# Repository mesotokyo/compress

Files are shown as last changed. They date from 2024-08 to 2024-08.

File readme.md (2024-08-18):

# MST Compress (Optical Compressor) schematic and PCB for KiCAD

(Japanese version is [here](readme_ja.md) / 日本語版は[こちら](readme_ja.md))

## What is this?

KiCAD files to build PCB of the MST Compress (Optical Compressor). These files are created with KiCad 6.0.

For more information about MST Compress, please check https://meso.tokyo/works/compress .

## Notice

This schematic and PCB file need a `ak_misc` footprint library in [mst-kicad-lib](https://github.com/mesotokyo/mst-kicad-lib). 

## DISCLAIMER

FILES IN THIS REPOSITORY ARE PROVIDED "AS IS", WITHOUT WARRANTY OF ANY KIND, EXPRESS OR IMPLIED, INCLUDING BUT NOT LIMITED TO THE WARRANTIES OF MERCHANTABILITY, FITNESS FOR A PARTICULAR PURPOSE AND NONINFRINGEMENT. IN NO EVENT SHALL THE AUTHORS OR COPYRIGHT HOLDERS BE LIABLE FOR ANY CLAIM, DAMAGES OR OTHER LIABILITY, WHETHER IN AN ACTION OF CONTRACT, TORT OR OTHERWISE, ARISING FROM, OUT OF OR IN CONNECTION WITH IN FILES IN THIS REPOSITORY OR THE USE OR OTHER DEALINGS IN FILES IN THIS REPOSITORY.

## License

CC BY 4.0. For more information, please check https://creativecommons.org/licenses/by/4.0/ .

## Author

MST/mesotokyo

 - https://meso.tokyo/
 - https://x.com/mesotokyox

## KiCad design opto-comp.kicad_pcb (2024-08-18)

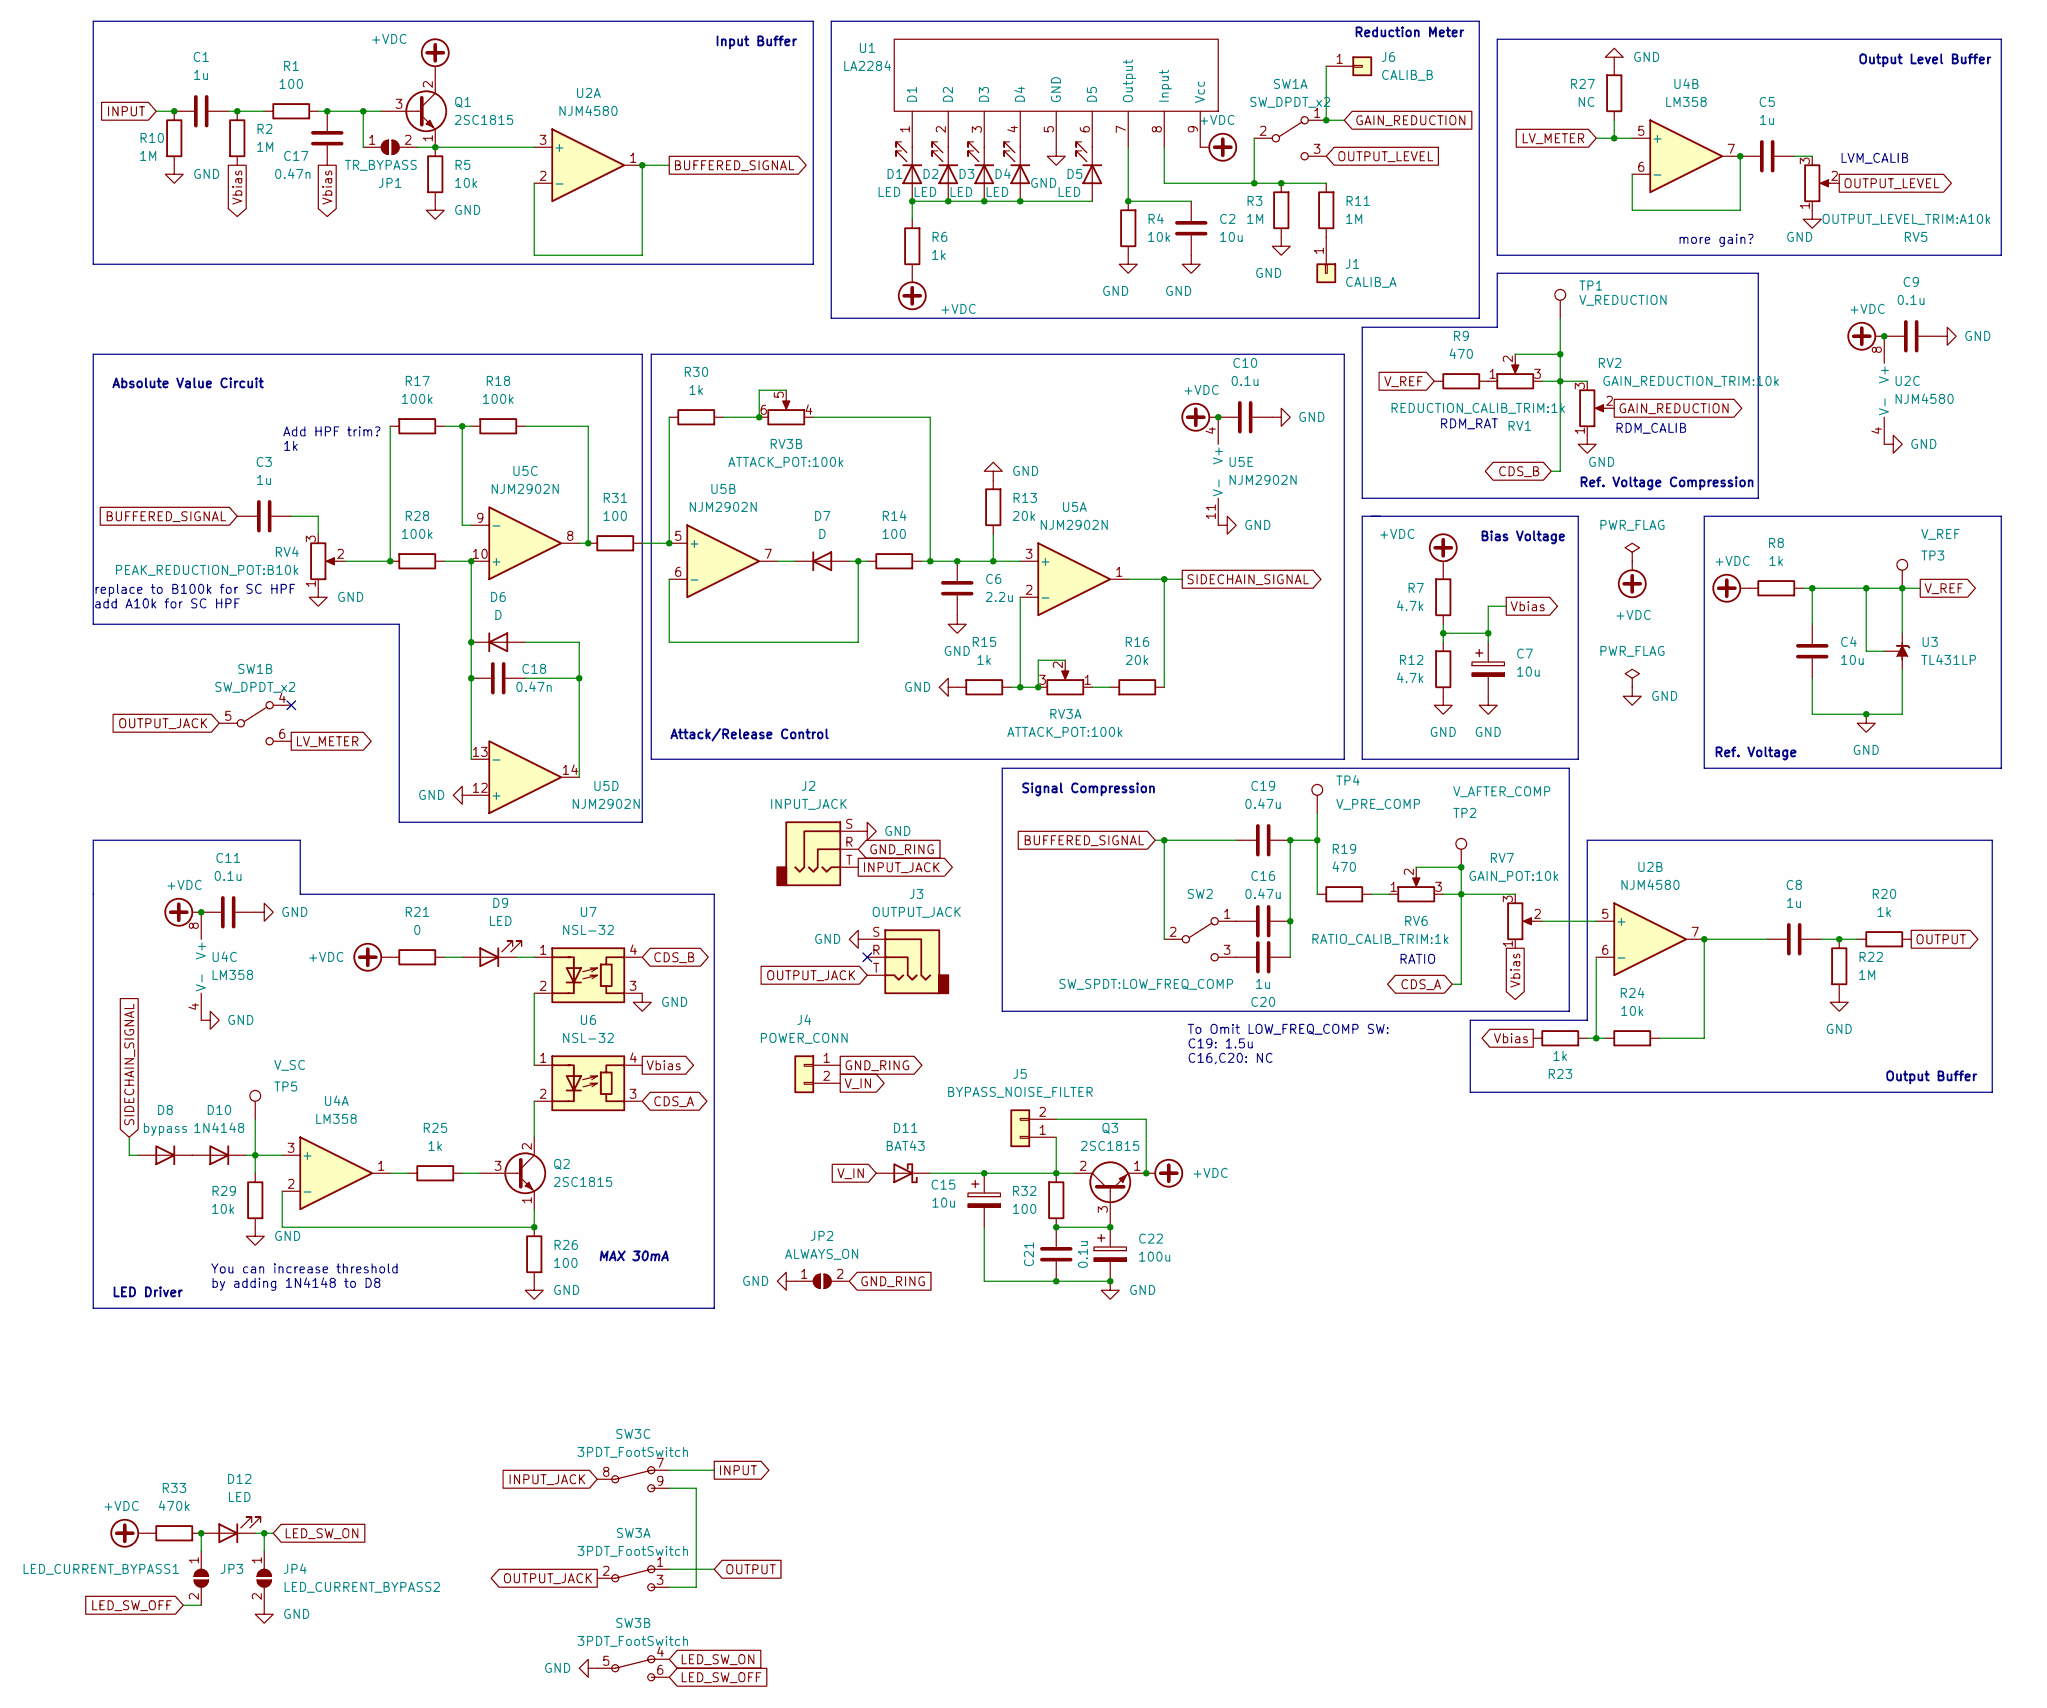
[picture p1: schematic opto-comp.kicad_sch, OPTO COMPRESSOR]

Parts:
C1, C3, C8, C20: 1u; C_Rect_L7.0mm_W6.0mm_P5.00mm
C2, C4: 10u; C_Disc_D6.0mm_W2.5mm_P5.00mm
C5: 1u; C_Disc_D3.0mm_W1.6mm_P2.50mm
C6: 2.2u; C_Rect_L7.0mm_W6.0mm_P5.00mm
C7, C15: 10u; CP_Radial_D5.0mm_P2.00mm
C9, C10, C11, C21: 0.1u; C_Disc_D3.0mm_W1.6mm_P2.50mm
C16, C19: 0.47u; C_Rect_L7.0mm_W6.0mm_P5.00mm
C17, C18: 0.47n; C_Disc_D3.0mm_W1.6mm_P2.50mm
C22: 100u; CP_Radial_D5.0mm_P2.00mm
D1, D2, D3, D4, D5, D9, D12: LED; LED_D3.0mm
D6, D7: D; D_DO-35_SOD27_P2.54mm_Vertical_AnodeUp
D8: bypass; D_DO-35_SOD27_P7.62mm_Horizontal
D10: 1N4148; D_DO-35_SOD27_P7.62mm_Horizontal
D11: BAT43; D_DO-35_SOD27_P7.62mm_Horizontal
J1: CALIB_A; PinHeader_1x01_P2.54mm_Vertical
J2: INPUT_JACK; MJ-187
J3: OUTPUT_JACK; MJ-187
J4: POWER_CONN; PinHeader_1x02_P2.54mm_Vertical
J5: BYPASS_NOISE_FILTER; PinHeader_1x02_P2.54mm_Vertical
J6: CALIB_B; PinHeader_1x01_P2.54mm_Vertical
JP1: TR_BYPASS; SolderJumper-2_P1.3mm_Open_RoundedPad1.0x1.5mm
JP2: ALWAYS_ON; SolderJumper-2_P1.3mm_Open_RoundedPad1.0x1.5mm
JP3: LED_CURRENT_BYPASS1; SolderJumper-2_P1.3mm_Open_RoundedPad1.0x1.5mm
JP4: LED_CURRENT_BYPASS2; SolderJumper-2_P1.3mm_Open_RoundedPad1.0x1.5mm
Q1, Q2, Q3: 2SC1815; TO-92_Inline
R1, R14, R26: 100; R_Axial_DIN0204_L3.6mm_D1.6mm_P2.54mm_Vertical
R2, R3, R10, R22: 1M; R_Axial_DIN0204_L3.6mm_D1.6mm_P2.54mm_Vertical
R4, R5, R24, R29: 10k; R_Axial_DIN0204_L3.6mm_D1.6mm_P2.54mm_Vertical
R6, R15, R20, R23, R25, R30: 1k; R_Axial_DIN0204_L3.6mm_D1.6mm_P2.54mm_Vertical
R7, R12: 4.7k; R_Axial_DIN0204_L3.6mm_D1.6mm_P7.62mm_Horizontal
R8: 1k; R_Axial_DIN0204_L3.6mm_D1.6mm_P7.62mm_Horizontal
R9: 470; R_Axial_DIN0204_L3.6mm_D1.6mm_P2.54mm_Vertical
R11: 1M; R_Axial_DIN0204_L3.6mm_D1.6mm_P7.62mm_Horizontal
R13, R16: 20k; R_Axial_DIN0204_L3.6mm_D1.6mm_P2.54mm_Vertical
R17, R18, R28: 100k; R_Axial_DIN0204_L3.6mm_D1.6mm_P2.54mm_Vertical
R19: 470; R_Axial_DIN0204_L3.6mm_D1.6mm_P7.62mm_Horizontal
R21: 0; R_Axial_DIN0204_L3.6mm_D1.6mm_P7.62mm_Horizontal
R27: NC; R_Axial_DIN0204_L3.6mm_D1.6mm_P7.62mm_Horizontal
R31, R32: 100; R_Axial_DIN0204_L3.6mm_D1.6mm_P7.62mm_Horizontal
R33: 470k; R_Axial_DIN0204_L3.6mm_D1.6mm_P2.54mm_Vertical
RV1: REDUCTION_CALIB_TRIM:1k; GF063
RV2: GAIN_REDUCTION_TRIM:10k; GF063
RV3: ATTACK_POT:100k; DualVR_AE-2VR-SW
RV4: PEAK_REDUCTION_POT:B10k; POT-16mm
RV5: OUTPUT_LEVEL_TRIM:A10k; GF063
RV6: RATIO_CALIB_TRIM:1k; GF063
RV7: GAIN_POT:10k; POT-16mm
SW1: SW_DPDT_x2; dpdt-sw-micro
SW2: SW_SPDT:LOW_FREQ_COMP; spdt-sw-micro
SW3: 3PDT_FootSwitch; 3PDT_FootSwitch_ovalpad
TP1: V_REDUCTION; TestPoint_THTPad_D2.0mm_Drill1.0mm
TP2: V_AFTER_COMP; TestPoint_THTPad_D2.0mm_Drill1.0mm
TP3: V_REF; TestPoint_THTPad_D2.0mm_Drill1.0mm
TP4: V_PRE_COMP; TestPoint_THTPad_D2.0mm_Drill1.0mm
TP5: V_SC; TestPoint_THTPad_D2.0mm_Drill1.0mm
U1: LA2284; SIP-9_22.3x3mm_P2.54mm
U2: NJM4580; DIP-8_W7.62mm_Socket
U3: TL431LP; TO-92_Inline
U4: LM358; DIP-8_W7.62mm_Socket
U5: NJM2902N; DIP-14_W7.62mm_Socket
U6, U7: NSL-32; LCR0202

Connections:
+VDC: C9.2, C10.2, C11.2, J5.2, Q1.2 (C), Q3.1 (E), R6.1, R7.2, R8.1, R21.1, R33.1, U1.9 (Vcc), U2.8 (V+), U4.8 (V+), U5.4 (V+)
BUFFERED_SIGNAL: C3.2, C19.2, SW2.2 (B), U2.1, U2.2 (-)
CDS_A: RV6.2, RV6.3, RV7.3, TP2.1, U6.3 (R)
CDS_B: RV1.2, RV1.3, RV2.3, TP1.1, U7.4 (R)
GAIN_REDUCTION: J6.1, RV2.2, SW1.1 (A)
GND: C2.2, C4.2, C6.1, C7.2, C9.1, C10.1, C11.1, C15.2, C21.1, C22.2, J2.S, J3.S, JP2.1 (A), JP4.2 (B), R3.1, R4.1, R5.2, R10.2, R12.1, R13.2, R15.2, R22.2, R26.2, R27.2, R29.2, RV2.1, RV4.1, RV5.1, SW3.5, U1.5 (GND), U2.4 (V-), U3.2 (A), U4.4 (V-), U5.11 (V-), U5.12 (+), U7.3 (R)
GND_RING: J2.R, J4.1, JP2.2 (B)
INPUT: C1.1, R10.1, SW3.7
INPUT_JACK: J2.T, SW3.8
LED_SW_OFF: JP3.2 (B), SW3.6
LED_SW_ON: D12.1 (K), JP4.1 (A), SW3.4
LV_METER: R27.1, SW1.6 (C), U4.5 (+)
unnamed: C1.2, R1.1, R2.1
unnamed: C2.1, R4.2, U1.7 (Output)
unnamed: C3.1, RV4.3
unnamed: C5.1, RV5.3
unnamed: C5.2, U4.6 (-), U4.7
unnamed: C6.2, R13.1, R14.2, RV3.4, U5.3 (+)
unnamed: C8.1, R24.2, U2.7
unnamed: C8.2, R20.1, R22.1
unnamed: C15.1, D11.1 (K), J5.1, Q3.2 (C), R32.2
unnamed: C16.1, C19.1, C20.1, R19.1, TP4.1
unnamed: C16.2, SW2.1 (A)
unnamed: C17.2, JP1.1 (A), Q1.3 (B), R1.2
unnamed: C18.1, D6.2 (A), U5.14
unnamed: C18.2, D6.1 (K), R28.1, U5.10 (+), U5.13 (-)
unnamed: C20.2, SW2.3 (C)
unnamed: C21.2, C22.1, Q3.3 (B), R32.1
unnamed: D1.1 (K), U1.1 (D1)
unnamed: D1.2 (A), D2.2 (A), D3.2 (A), D4.2 (A), D5.2 (A), R6.2
unnamed: D2.1 (K), U1.2 (D2)
unnamed: D3.1 (K), U1.3 (D3)
unnamed: D4.1 (K), U1.4 (D4)
unnamed: D5.1 (K), U1.6 (D5)
unnamed: D7.1 (K), U5.7
unnamed: D7.2 (A), R14.1, U5.6 (-)
unnamed: D9.1 (K), U7.1 (A)
unnamed: D9.2 (A), R21.2
unnamed: D10.1 (K), R29.1, TP5.1, U4.3 (+)
unnamed: D8.1 (K), D10.2 (A)
unnamed: D12.2 (A), JP3.1 (A), R33.2
unnamed: J1.1, R11.1
unnamed: JP1.2 (B), Q1.1 (E), R5.1, U2.3 (+)
unnamed: Q2.1 (E), R26.1, U4.2 (-)
unnamed: Q2.2 (C), U6.2 (K)
unnamed: Q2.3 (B), R25.2
unnamed: R9.2, RV1.1
unnamed: R3.2, R11.2, SW1.2 (B), U1.8 (Input)
unnamed: R15.1, RV3.2, RV3.3, U5.2 (-)
unnamed: R16.2, RV3.1
unnamed: R17.1, R18.2, U5.9 (-)
unnamed: R17.2, R28.2, RV4.2
unnamed: R18.1, R31.1, U5.8
unnamed: R19.2, RV6.1
unnamed: R23.2, R24.1, U2.6 (-)
unnamed: R25.1, U4.1
unnamed: R30.1, R31.2, U5.5 (+)
unnamed: R30.2, RV3.5, RV3.6
unnamed: RV7.2, U2.5 (+)
unnamed: SW3.3, SW3.9
unnamed: U6.1 (A), U7.2 (K)
OUTPUT: R20.2, SW3.1
OUTPUT_JACK: J3.T, SW1.5 (B), SW3.2
OUTPUT_LEVEL: RV5.2, SW1.3 (C)
SIDECHAIN_SIGNAL: D8.2 (A), R16.1, U5.1
V_IN: D11.2 (A), J4.2
V_REF: C4.1, R8.2, R9.1, TP3.1, U3.1 (REF), U3.3 (K)
Vbias: C7.1, C17.1, R2.2, R7.1, R12.2, R23.1, RV7.1, U6.4 (R)

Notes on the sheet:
LVM_CALIB
Signal Compression
Reduction Meter
LED Driver
Ref. Voltage
RATIO
MAX 30mA
RDM_RAT
Bias Voltage
Attack/Release Control
Output Level Buffer
Output Buffer
Absolute Value Circuit
RDM_CALIB
more gain?
You can increase threshold by adding 1N4148 to D8
Ref. Voltage Compression
Add HPF trim? 1k
To Omit LOW_FREQ_COMP SW: C19: 1.5u C16,C20: NC
replace to B100k for SC HPF add A10k for SC HPF
Input Buffer

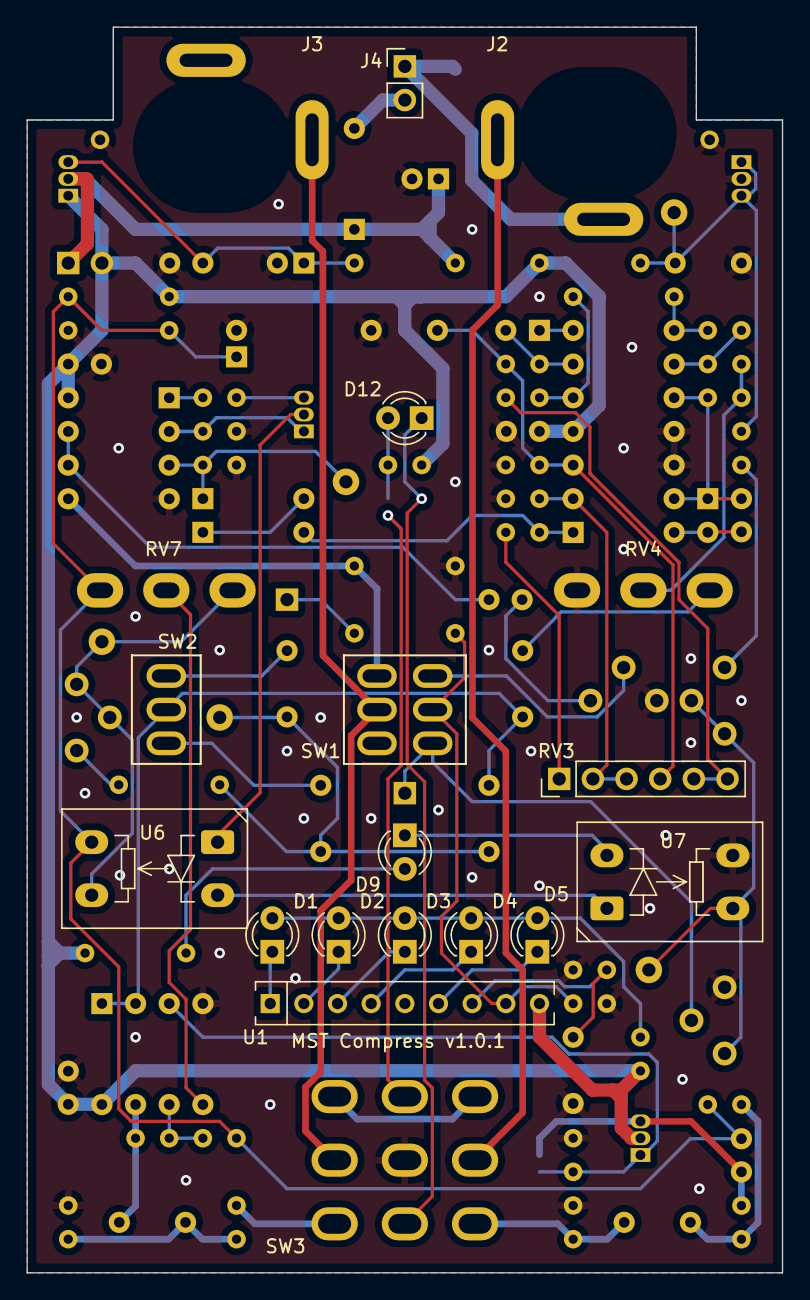
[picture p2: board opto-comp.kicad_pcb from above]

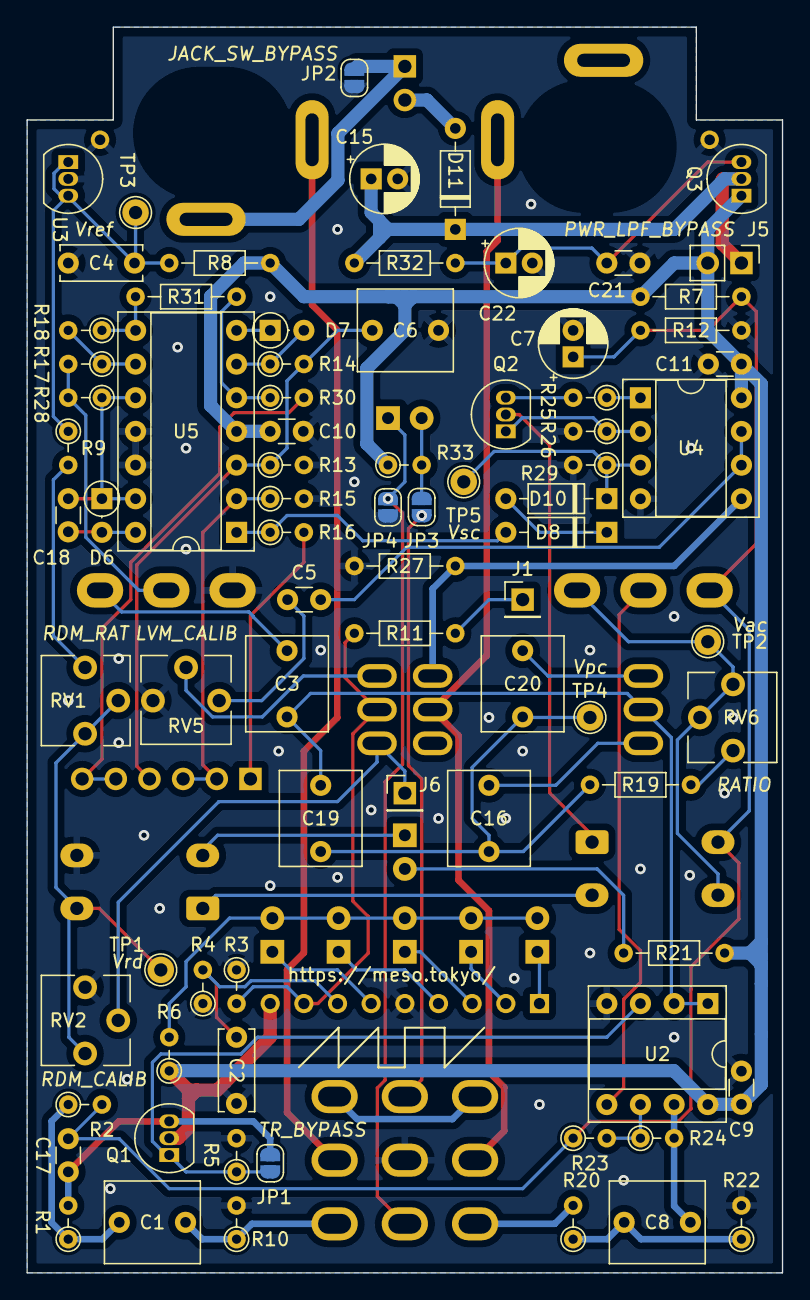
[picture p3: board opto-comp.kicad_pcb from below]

Board: 2 copper layers, 57.0 x 94.0 mm, 99 parts (80 on the bottom side), 68 nets.

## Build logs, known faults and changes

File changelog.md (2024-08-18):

# Changelog

## v1.0.1 - 2024-08-18

 * Fix LCR-2020 footprint pattern
 * Add version information and credit
 * Replace LM324 to NJM2902N

## v1.0.0 - 2024-01-27

This is first internal version.

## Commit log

2024-08-18 fix LCR pattern, add credit
    [opto-comp.kicad_pcb, opto-comp.kicad_sch]
2024-08-18 Replace LM324 to NJM2902N
    [opto-comp.kicad_pcb, opto-comp.kicad_sch]
